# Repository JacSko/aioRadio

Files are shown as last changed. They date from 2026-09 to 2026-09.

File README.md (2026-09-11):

# aioRadio

## Project description
aioRadio (all-in-one Radio) is the ESP32-based system designed for FM, DAB and Online radio reception. It is based on Silicon Labs Si4684 chipset capable 
of decoding analog and digital radio. System consist of:
- Main custom-designed PCB with antenna input and 3,5mm jack audio output,
- st7796 480x320 LCD
- Rotary encoder with integrated push button

## Key features
- FM and DAB radio support
- Station list
- Band scan

## Building
System is based on esp-idf framework and works under freeRTOS control.

### Preconditions:
- download esp-idf toolchain
- source export.sh
### Build target
- go into project root directory and run:
```
./build_app.sh
```

### Build unit tests 
- go into project root directory and run:
```
./build_ut.sh
```



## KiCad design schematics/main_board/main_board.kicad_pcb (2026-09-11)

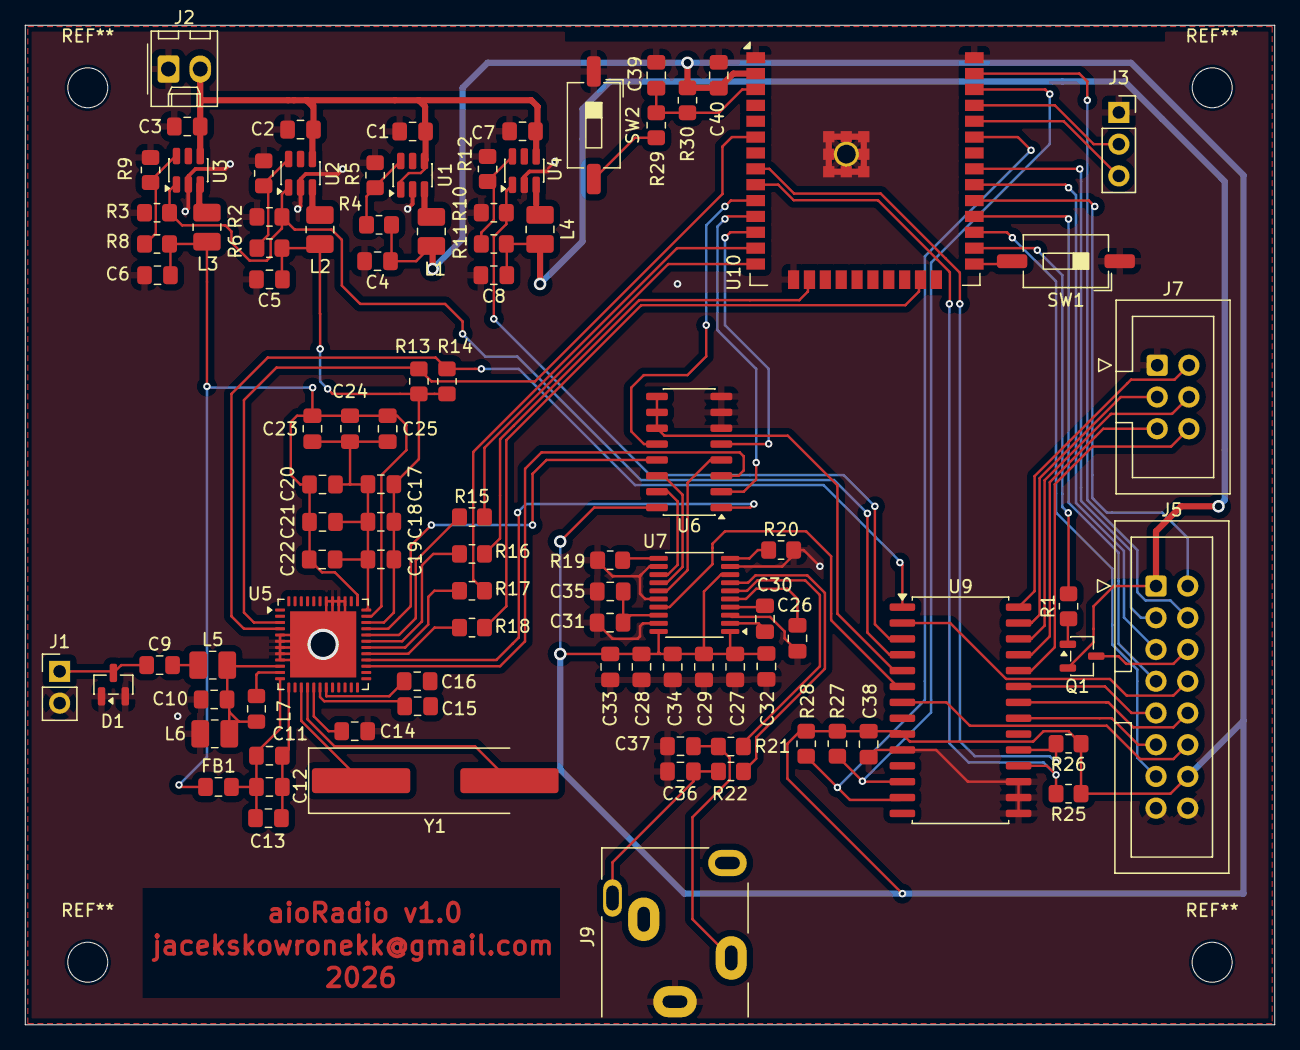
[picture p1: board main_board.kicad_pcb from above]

Board: 2 copper layers, 100.0 x 80.0 mm, 96 parts (0 on the bottom side), 87 nets.

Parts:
C1, C2, C3, C7: 4.7uF; C_0805_2012Metric_Pad1.18x1.45mm_HandSolder
C4, C5, C6, C8: 10uF; C_0805_2012Metric_Pad1.18x1.45mm_HandSolder
C9: 33p; C_0805_2012Metric_Pad1.18x1.45mm_HandSolder
C10: 2,7pF; C_0805_2012Metric_Pad1.18x1.45mm_HandSolder
C11, C27, C28, C29, C31, C38, C40: 100n; C_0805_2012Metric_Pad1.18x1.45mm_HandSolder
C12, C18, C21, C24: 2,2pF; C_0805_2012Metric_Pad1.18x1.45mm_HandSolder
C13, C17, C20, C23: 8,2pF; C_0805_2012Metric_Pad1.18x1.45mm_HandSolder
C14, C15, C16, C19, C22, C25, C39: 1u; C_0805_2012Metric_Pad1.18x1.45mm_HandSolder
C26, C30: 2,2uF; C_0805_2012Metric_Pad1.18x1.45mm_HandSolder
C32, C33, C34, C35: 10u; C_0805_2012Metric_Pad1.18x1.45mm_HandSolder
C36, C37: 2.2n; C_0805_2012Metric_Pad1.18x1.45mm_HandSolder
D1: BAV99; SOT-23
FB1: 1k; C_0805_2012Metric_Pad1.18x1.45mm_HandSolder
J1: ANT; PinHeader_1x02_P2.54mm_Vertical
J2: VCC_INPUT_5V0; Molex_KK-254_AE-6410-02A_1x02_P2.54mm_Vertical
J3: UART; PinSocket_1x03_P2.54mm_Vertical
J5: CONTROL_BOARD; IDC-Header_2x08_P2.54mm_Vertical
J7: GPIO_EXT; IDC-Header_2x03_P2.54mm_Vertical
J9: LineOut; Jack_3.5mm_CUI_SJ1-3515N_Horizontal
L1, L2, L3, L4: 2.2uH; L_1008_2520Metric_Pad1.43x2.20mm_HandSolder
L5: 18nH; L_1008_2520Metric_Pad1.43x2.20mm_HandSolder
L6: 120nH; L_1008_2520Metric_Pad1.43x2.20mm_HandSolder
L7: 22nH; L_0805_2012Metric_Pad1.15x1.40mm_HandSolder
Q1: BC807; SOT-23-3
R1: 330R; R_0805_2012Metric_Pad1.20x1.40mm_HandSolder
R2, R3, R10, R13, R14, R25, R26, R27, R28, R30: 10k; R_0805_2012Metric_Pad1.20x1.40mm_HandSolder
R4, R6, R11: 464k; R_0805_2012Metric_Pad1.20x1.40mm_HandSolder
R5, R7, R9, R12: 100k; R_0805_2012Metric_Pad1.20x1.40mm_HandSolder
R8: 200k; R_0805_2012Metric_Pad1.20x1.40mm_HandSolder
R15, R16, R17, R18: 100; R_0805_2012Metric_Pad1.20x1.40mm_HandSolder
R19, R20, R29: 0; R_0805_2012Metric_Pad1.20x1.40mm_HandSolder
R21, R22: 470R; R_0805_2012Metric_Pad1.20x1.40mm_HandSolder
SW1: BOOT_MODE; SW_DIP_SPSTx01_Slide_6.7x4.1mm_W8.61mm_P2.54mm_LowProfile
SW2: RESET; SW_DIP_SPSTx01_Slide_6.7x4.1mm_W8.61mm_P2.54mm_LowProfile
U1, U2, U3, U4: TLV62569DDC; SOT-23-6
U5: SI4684 SMD; QFN-48-1EP_7x7mm_P0.5mm_EP5.3x5.3mm
U6: CD74HC5053; SO-16_3.9x9.9mm_P1.27mm
U7: PCM5102; TSSOP-20_4.4x6.5mm_P0.65mm
U9: MCP23017_SO; SOIC-28W_7.5x17.9mm_P1.27mm
U10: ESP32-WROOM-32E; ESP32-WROOM-32E_handsolder
Y1: Crystal; Crystal_SMD_HC49-SD_HandSoldering

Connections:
/Audio/DAC_MUTE: U7.17 (XSMT), U9.6 (GPB5)
/Audio/I2S_SOURCE_SEL: U6.9 (S3), U6.10 (S2), U6.11 (S1), U9.5 (GPB4)
/Audio/SOC_I2S_DCLK: U6.2 (B0), U10.11 (IO26)
/Audio/SOC_I2S_DFS: U6.5 (C0), U10.12 (IO27)
/Audio/SOC_I2S_DIN: U6.12 (A0), U10.10 (IO25)
/Audio/TUNER_I2S_DCLK: U5.28 (DSF), U6.1 (B1)
/Audio/TUNER_I2S_DFS: U5.27 (DCLK), U6.3 (C1)
/Audio/TUNER_I2S_DIN: U5.33 (DOUT), U6.13 (A1)
/Audio/VCC_3V3: C4.1, C27.1, C28.1, C29.1, C32.1, C33.1, C34.1, C38.1, C40.1, J5.14, L1.2, R4.1, R25.1, R26.1, R27.1, R28.1, R30.1, U6.16 (VDD), U7.1 (CPVDD), U7.8 (AVDD), U7.20 (DVDD), U9.9 (VDD), U10.2 (VDD)
/BTN: J5.9, U9.23 (GPA2)
/DATA_REG: J5.7, U10.28 (IO17)
/ENC_A: J5.10, U9.22 (GPA1)
/ENC_B: J5.11, U9.21 (GPA0)
/ENC_BNT: J5.12, U9.7 (GPB6)
/IR: J5.13, U10.27 (IO16)
/LED_PWM: J5.6, Q1.3 (C)
/PSU/PWR_DISPLAY_3V3: C8.1, J5.1, L4.2, Q1.2 (E), R11.1
/PSU/PWR_DISPLAY_EN: R10.1, U4.1 (EN), U9.3 (GPB2)
/PSU/PWR_TUNER_1V8: C6.1, C20.2, C21.2, C22.2, C23.2, C24.2, C25.2, FB1.1, L3.2, R8.1, U5.35 (VMEM), U5.37 (VCORE)
/PSU/PWR_TUNER_3V3: C5.1, C17.2, C18.2, C19.2, L2.2, R6.1, R13.1, R14.1, U5.34 (VIO)
/PSU/PWR_TUNER_EN: R2.1, R3.1, U2.1 (EN), U3.1 (EN), U9.4 (GPB3)
/PSU/VCC_INPUT_5V0: C1.1, C2.1, C3.1, C7.1, J2.2, U1.1 (EN), U1.4 (VIN), U2.4 (VIN), U3.4 (VIN), U4.4 (VIN)
/RESET: J5.8, U9.2 (GPB1)
/SOC/DISPLAY_LED_PWM: R1.2, U10.26 (IO4)
/SOC/EXP_I2C_SCK: R27.2, U9.12 (SCK), U10.36 (IO22)
/SOC/EXP_I2C_SDA: R28.2, U9.13 (SDA), U10.33 (IO21)
/SOC/EXP_i2C_INT: R26.2, U9.19 (INTB), U10.8 (IO32)
/SOC/EXP_i2C_RESET: R25.2, U9.18 (~RESET), U10.9 (IO33)
/SOC/SOC_BOOT: SW1.2, U10.25 (IO0)
/SOC/SOC_RESET: R29.2, SW2.2
/SOC/SOC_UART_RX: J3.3, U10.34 (RXD0/IO3)
/SOC/SOC_UART_TX: J3.2, U10.35 (TXD0/IO1)
/SPI_CLK: J5.5, U10.30 (IO18)
/SPI_CS: J5.2, U10.29 (IO5)
/SPI_MISO: J5.3, U10.31 (IO19)
/SPI_MOSI: J5.4, U10.37 (IO23)
/TUNER_CLK: R17.2, U10.13 (IO14)
/TUNER_CS: R18.2, U10.23 (IO15)
/TUNER_INT: R13.2, U5.3 (~INTB), U10.6 (IO34)
/TUNER_MISO: R15.2, U10.14 (IO12)
/TUNER_MOSI: R16.2, U10.16 (IO13)
/TUNER_RESET: R14.2, U5.4 (~RSTB), U9.1 (GPB0)
/Tuner/ANT_IN: C9.1, D1.3 (K), J1.1 (In)
GND: C1.2, C2.2, C3.2, C4.2, C5.2, C6.2, C7.2, C8.2, C10.2, C14.2, C26.2, C27.2, C28.2, C29.2, C31.2, C32.2, C33.2, C34.2, C35.2, C36.2, C37.2, C38.2, C39.2, C40.2, D1.1 (K), D1.2 (A), J1.2 (Ext), J2.1, J3.1, J5.15, J5.16, J7.1, J9.S, L6.2, R2.2, R3.2, R5.2, R7.2, R9.2, R10.2, R12.2, R19.1, R20.2, SW1.1, SW2.1, U1.2 (GND), U2.2 (GND), U3.2 (GND), U4.2 (GND), U5.5 (SMODE), U5.6 (RFREF), U5.7 (RFREF), U5.8 (RFREF), U5.9 (RFREF), U5.39 (GNDD), U5.40 (GNDD), U5.41 (GNDD), U5.42 (GNDD), U5.49 (GND), U6.6 (INH), U6.7 (VEE), U6.8 (VSS), U7.3 (CPGND), U7.9 (AGND), U7.12 (SCK), U7.16 (FMT), U7.19 (DGND), U9.10 (VSS), U9.15 (A0), U9.16 (A1), U9.17 (A2), U10.1 (GND), U10.15 (GND), U10.38 (GND), U10.39 (GND)
unnamed: C9.2, L5.1
unnamed: C36.1, J9.R, R22.1
unnamed: C37.1, J9.T, R21.2
unnamed: J7.2, U9.28 (GPA7)
unnamed: J7.3, U9.27 (GPA6)
unnamed: J7.4, U9.26 (GPA5)
unnamed: J7.5, U9.25 (GPA4)
unnamed: J7.6, U9.24 (GPA3)
unnamed: Q1.1 (B), R1.1
unnamed: R4.2, R5.1, U1.6 (FB)
unnamed: L1.1, U1.3 (SW)
unnamed: R6.2, R7.1, U2.6 (FB)
unnamed: L2.1, U2.3 (SW)
unnamed: R8.2, R9.1, U3.6 (FB)
unnamed: L3.1, U3.3 (SW)
unnamed: R11.2, R12.1, U4.6 (FB)
unnamed: L4.1, U4.3 (SW)
unnamed: C11.2, C12.2, C13.2, U5.13 (ABYP)
unnamed: C14.1, U5.17 (DACREF)
unnamed: C17.1, C18.1, C19.1, C20.1, C21.1, C22.1, C23.1, C24.1, C25.1, U5.36 (DBYP)
unnamed: C15.1, U5.18 (LOUT)
unnamed: R15.1, U5.32 (MISO)
unnamed: R16.1, U5.31 (MOSI)
unnamed: C16.1, U5.19 (ROUT)
unnamed: R17.1, U5.30 (SCLK)
unnamed: R18.1, U5.29 (SSB)
unnamed: C11.1, C12.1, C13.1, FB1.2, U5.12 (VA)
unnamed: C10.1, L5.2, L6.1, L7.1, U5.10 (VHFI)
unnamed: L7.2, U5.11 (VHFSW)
unnamed: U5.15 (XTALI), Y1.1
unnamed: U5.16 (XTALO), Y1.2
unnamed: U6.14 (A), U7.14 (DIN)
unnamed: U6.15 (B), U7.13 (BCK)
unnamed: U6.4 (C), U7.15 (LRCK)
unnamed: C30.2, U7.4 (CAPM)
unnamed: C30.1, U7.2 (CAPP)
unnamed: R20.1, U7.10 (DEMP)
unnamed: R19.2, U7.11 (FLT)
unnamed: C31.1, C35.1, U7.18 (LDOO)
unnamed: R21.1, U7.6 (OUTL)
unnamed: R22.2, U7.7 (OUTR)
unnamed: C26.1, U7.5 (VNEG)
unnamed: C39.1, R29.1, R30.2, U10.3 (EN)

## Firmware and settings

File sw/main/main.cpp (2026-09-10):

#include <thread>
#include <memory>
#include <chrono>
#include "Log.h"
#include "GPIOProvider.h"
#include "GPIOMapping.h"
#include "IDeviceDriver.h"
#include "TunerManager.h"
#include "IDABTuner.h"
#include "IFMTuner.h"
#include "UserControl.h"
#include "DisplayDriver.h"
#include "IAudioControl.h"

#include "esp_heap_caps.h"

static const char* TAG = "AIO_RADIO";
using namespace drivers;

class aioRadio : public drivers::encoder::IEncoderListener
{
public:
   aioRadio():
   m_provider(gpio::mcp23017::i2cConfig{
            .i2cAddress = 0x20,
            .clockSpeedHz = 400000,
            .sclPin = static_cast<uint16_t>(drivers::gpio::GPIO::GPIO_I2C_SCL),
            .sdaPin = static_cast<uint16_t>(drivers::gpio::GPIO::GPIO_I2C_SDA),
            .resetPin = static_cast<uint16_t>(drivers::gpio::GPIO::GPIO_I2C_RESET),
            .interruptPin = static_cast<uint16_t>(drivers::gpio::GPIO::GPIO_I2C_INT),
             }),
   m_displayDriver(m_provider)
   {

   }
   void onEvent(const drivers::encoder::IEncoderListener::Event& event) override
   {
      AIO_LOGE(TAG, "Encoder event received: type=%s, diff=%d", drivers::encoder::IEncoderListener::eventName(event.type), event.diff);
   }
   void run()
   {
      bool result = false;

      result = m_displayDriver.initialize();
      AIO_LOGI(TAG, "DisplayDriver init resultL: %d", result);

      m_mainGUI = display::gui::IMainGUI::create();
      m_mainGUI->initialize(display::gui::ViewType::DAB);
      AIO_LOGI(TAG, "MainGUI created!");

      m_tunerDriver = tuner::devicedriver::IDeviceDriver::create(m_provider);
      result = m_tunerDriver->initialize();
      AIO_LOGI(TAG, "Device driver init result: %d", result);

      m_dabTuner = tuner::dab::IDABTuner::create(*m_tunerDriver);
      AIO_LOGI(TAG, "DABTuner created!");

      m_fmTuner = tuner::fm::IFMTuner::create(*m_tunerDriver);
      AIO_LOGI(TAG, "FMTuner created!");

      m_audioControl = audio::IAudioControl::create(*m_tunerDriver);
      AIO_LOGI(TAG, "AudioControl created!");

      m_userControl = std::make_unique<control::UserControl>(m_provider.getDriver(), *m_mainGUI, *m_audioControl);
      AIO_LOGI(TAG, "UserControl created!");

      m_tunerManager = std::make_unique<tuner::manager::TunerManager>(*m_mainGUI, *m_dabTuner, *m_fmTuner, *m_audioControl);

      while(1)
      {
         std::this_thread::sleep_for(std::chrono::milliseconds(1000));
      }
   }
private:
   gpio::GPIOProvider m_provider;
   display::driver::DisplayDriver m_displayDriver;
   std::unique_ptr<display::gui::IMainGUI> m_mainGUI;
   std::unique_ptr<audio::IAudioControl> m_audioControl;
   std::unique_ptr<control::UserControl> m_userControl;
   std::unique_ptr<tuner::devicedriver::IDeviceDriver> m_tunerDriver;
   std::unique_ptr<tuner::dab::IDABTuner> m_dabTuner;
   std::unique_ptr<tuner::fm::IFMTuner> m_fmTuner;
   std::unique_ptr<tuner::manager::TunerManager> m_tunerManager;
};

extern "C" void app_main(void )
{
   // AIO_LOGE(TAG, "[before aioReadio creation] Free heap: %zu, largest block: %zu", heap_caps_get_free_size(MALLOC_CAP_DEFAULT), heap_caps_get_largest_free_block(MALLOC_CAP_DEFAULT));
   aioRadio radio;
   // AIO_LOGE(TAG, "[after aioRadio creation] Free heap: %zu, largest block: %zu", heap_caps_get_free_size(MALLOC_CAP_DEFAULT), heap_caps_get_largest_free_block(MALLOC_CAP_DEFAULT));
   radio.run();
}

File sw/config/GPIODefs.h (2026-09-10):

#pragma once
#include <cstdint>

namespace drivers::gpio {

   static constexpr uint16_t SOC_GPIO0    = 0;
   static constexpr uint16_t SOC_GPIO2    = 2;
   static constexpr uint16_t SOC_GPIO4    = 4;
   static constexpr uint16_t SOC_GPIO5    = 5;
   static constexpr uint16_t SOC_GPIO12   = 12;
   static constexpr uint16_t SOC_GPIO13   = 13;
   static constexpr uint16_t SOC_GPIO14   = 14;
   static constexpr uint16_t SOC_GPIO15   = 15;
   static constexpr uint16_t SOC_GPIO16   = 16;
   static constexpr uint16_t SOC_GPIO17   = 17;
   static constexpr uint16_t SOC_GPIO18   = 18;
   static constexpr uint16_t SOC_GPIO19   = 19;
   static constexpr uint16_t SOC_GPIO20   = 20;
   static constexpr uint16_t SOC_GPIO21   = 21;
   static constexpr uint16_t SOC_GPIO22   = 22;
   static constexpr uint16_t SOC_GPIO23   = 23;
   static constexpr uint16_t SOC_GPIO25   = 25;
   static constexpr uint16_t SOC_GPIO26   = 26;
   static constexpr uint16_t SOC_GPIO27   = 27;
   static constexpr uint16_t SOC_GPIO32   = 32;
   static constexpr uint16_t SOC_GPIO33   = 33;
   static constexpr uint16_t SOC_GPIO34   = 34;
   static constexpr uint16_t SOC_GPIO_MAX = 0x9F;
   static constexpr uint16_t I2C_GPIOA0   = 0xA0;
   static constexpr uint16_t I2C_GPIOA1   = 0xA1;
   static constexpr uint16_t I2C_GPIOA2   = 0xA2;
   static constexpr uint16_t I2C_GPIOA3   = 0xA3;
   static constexpr uint16_t I2C_GPIOA4   = 0xA4;
   static constexpr uint16_t I2C_GPIOA5   = 0xA5;
   static constexpr uint16_t I2C_GPIOA6   = 0xA6;
   static constexpr uint16_t I2C_GPIOA7   = 0xA7;
   static constexpr uint16_t I2C_GPIOB0   = 0xB0;
   static constexpr uint16_t I2C_GPIOB1   = 0xB1;
   static constexpr uint16_t I2C_GPIOB2   = 0xB2;
   static constexpr uint16_t I2C_GPIOB3   = 0xB3;
   static constexpr uint16_t I2C_GPIOB4   = 0xB4;
   static constexpr uint16_t I2C_GPIOB5   = 0xB5;
   static constexpr uint16_t I2C_GPIOB6   = 0xB6;
   static constexpr uint16_t I2C_GPIOB7   = 0xB7;
   static constexpr uint16_t I2C_GPIO_MAX = 0xFF;

}

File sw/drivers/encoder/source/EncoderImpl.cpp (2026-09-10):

#include "EncoderImpl.h"
#include "Log.h"

namespace drivers::encoder
{
using namespace gpio;

static const char* TAG = "Encoder";
static const int TASK_STACK_SIZE = 4096;
static const int TASK_NOTIFY_WAIT_MS = 1000;
static const int TASK_PRIORITY = 2;
static const mcp23017::PIN PIN_A = mcp23017::PIN::GPIOA1;
static const mcp23017::PIN PIN_B = mcp23017::PIN::GPIOA0;
static const mcp23017::PIN PIN_BUTTON = mcp23017::PIN::GPIOB6;

std::unique_ptr<IEncoder> IEncoder::create(drivers::gpio::mcp23017::IMCP23017& driver, IEncoderListener& listener)
{
    return std::make_unique<EncoderImpl>(driver, listener);
}

static void mcp_gpio_listener(mcp23017::PIN pin, bool state , void* arg)
{
   EncoderImpl* enc = static_cast<EncoderImpl*>(arg);
   enc->onInterrupt(pin, state);
}

EncoderImpl::EncoderImpl(drivers::gpio::mcp23017::IMCP23017& driver, IEncoderListener& listener):
m_driver(driver),
m_listener(listener),
m_edgesMutex(xSemaphoreCreateMutex())
{
   AIO_ASSERT(m_edgesMutex != nullptr, TAG, "Failed to create listeners mutex");
   openEncoderPin(PIN_A);
   openEncoderPin(PIN_B);
   openEncoderPin(PIN_BUTTON);
}
EncoderImpl::~EncoderImpl()
{
   closeEncoderPin(PIN_A);
   closeEncoderPin(PIN_B);
   closeEncoderPin(PIN_BUTTON);
}
void EncoderImpl::openEncoderPin(mcp23017::PIN pin)
{
   m_driver.setPullup(pin, mcp23017::Pullup::ENABLED);
   m_driver.setInterruptCompare(pin, mcp23017::InterruptCompare::COMPARE_PREVIOUS);
   m_driver.setDirection(pin,mcp23017::Direction::INPUT);
   m_driver.setListener(pin, mcp_gpio_listener, this);
}
void EncoderImpl::closeEncoderPin(mcp23017::PIN pin)
{
   m_driver.removeListener(pin);
}
void EncoderImpl::onInterrupt(mcp23017::PIN pin, bool state)
{
   IEncoderListener::Event event = {};
   switch(pin)
   {
      case PIN_A:
         AIO_LOGD(TAG, "Interrupt on encoder pin A, state: %d", static_cast<int>(state));
         xSemaphoreTake(m_edgesMutex, portMAX_DELAY);
         m_lastEdges <<= 8;
         m_lastEdges |= state ? PIN_A_RISING : PIN_A_FALLING;
         checkEncoderMove();
         xSemaphoreGive(m_edgesMutex);
         break;
      case PIN_B:
         AIO_LOGD(TAG, "Interrupt on encoder pin B, state: %d", static_cast<int>(state));
         xSemaphoreTake(m_edgesMutex, portMAX_DELAY);
         m_lastEdges <<= 8;
         m_lastEdges |= state? PIN_B_RISING : PIN_B_FALLING;
         checkEncoderMove();
         xSemaphoreGive(m_edgesMutex);
         break;
      case PIN_BUTTON:
         AIO_LOGD(TAG, "Interrupt on encoder button, state: %d", static_cast<int>(state));
         event.type = state? IEncoderListener::Event::Type::BUTTON_RELEASED:
                             IEncoderListener::Event::Type::BUTTON_PRESSED;
         event.diff = 0;
         m_listener.onEvent(event);
         break;
      default:
         AIO_LOGW(TAG, "Interrupt on unknown GPIO ID: %.2x", static_cast<int>(pin));
         break;
   }
}
void EncoderImpl::checkEncoderMove()
{
   static const uint32_t CW_PATTERN = (PIN_A_FALLING << 24) | (PIN_B_FALLING << 16) | (PIN_A_RISING << 8) | (PIN_B_RISING);
   static const uint32_t CCW_PATTERN = (PIN_B_FALLING << 24) | (PIN_A_FALLING << 16) | (PIN_B_RISING << 8) | (PIN_A_RISING);

   if (m_lastEdges == CW_PATTERN)
   {
      IEncoderListener::Event event = {};
      event.type = IEncoderListener::Event::Type::ROTATE;
      event.diff = -1;
      m_listener.onEvent(event);
      m_lastEdges = 0;
   }
   else if (m_lastEdges == CCW_PATTERN)
   {
      IEncoderListener::Event event = {};
      event.type = IEncoderListener::Event::Type::ROTATE;
      event.diff = 1;
      m_listener.onEvent(event);
      m_lastEdges = 0;
   }
}

} // namespace drivers

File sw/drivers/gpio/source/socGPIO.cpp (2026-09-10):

#include <vector>

#include "socGPIO.h"
#include "TableConverter.hpp"
#include "driver/gpio.h"
#include "Log.h"

namespace drivers::gpio
{

static const char* TAG = "socGPIO";
static const int TASK_STACK_SIZE = 4096;
static const int TASK_NOTIFY_WAIT_MS = 1000;
static const int TASK_PRIORITY = 2;

static void IRAM_ATTR gpio_soc_isr_handler(void* arg)
{
   socGPIO* gpio = static_cast<socGPIO*>(arg);
   gpio->onInterrupt();
}

static void taskFunction(void* arg)
{
   socGPIO* gpio = static_cast<socGPIO*>(arg);
   gpio->task();
   vTaskDelete(NULL);
}

socGPIO::socGPIO(uint16_t id, const std::string&& name) :
m_id(id),
m_name(std::move(name)),
m_task(nullptr),
m_listenersMutex(xSemaphoreCreateMutex())
{
   AIO_LOGI(TAG, "[%s] creating", m_name.c_str());
   assert(m_listenersMutex != nullptr);
   gpio_reset_pin(static_cast<gpio_num_t>(m_id));
}
socGPIO::~socGPIO()
{
   AIO_LOGI(TAG, "[%s] destroying", m_name.c_str());
   disableInterrupts();
   gpio_reset_pin(static_cast<gpio_num_t>(m_id));
}
void socGPIO::onInterrupt()
{
   //This method is called in ISR context
   ESP_DRAM_LOGE(DRAM_STR("SOC"), "task notify from ISR for GPIO %u", static_cast<unsigned int>(m_id));
   vTaskNotifyGiveFromISR(m_task, nullptr);
}
void socGPIO::task()
{
   for (;;)
   {
      int eventReady = ulTaskNotifyTake(true, pdMS_TO_TICKS(TASK_NOTIFY_WAIT_MS));
      if (eventReady)
      {
         handleInterrupt();
      }
   }
}
void socGPIO::handleInterrupt()
{
   AIO_LOGV(TAG, "[%s] interrupt received, reading state...", m_name.c_str());
   int level = gpio_get_level(static_cast<gpio_num_t>(m_id));
   AIO_LOGV(TAG, "[%s] is %u, calling listeners...", m_name.c_str(), level);
   xSemaphoreTake(m_listenersMutex, portMAX_DELAY);
   if (m_listener)
   {
      m_listener->onInterrupt(static_cast<GPIO>(m_id), static_cast<State>(level ?
                                                       State::HIGH :
                                                       State::LOW));
   }
   xSemaphoreGive(m_listenersMutex);
}
bool socGPIO::createTask()
{
   AIO_LOGI(TAG, "[%s] creating interrupt task", m_name.c_str());
   char taskName[16];
   snprintf(taskName, sizeof(taskName), "socGPIO_%u", static_cast<unsigned int>(m_id));
   BaseType_t result = xTaskCreate(taskFunction, taskName, TASK_STACK_SIZE, this, TASK_PRIORITY, &m_task);
   AIO_LOGE_IF(result != pdPASS, TAG, "[%s] Failed to create interrupt task, error %d", m_name.c_str(), result);
   return result == pdPASS;
}
void socGPIO::destroyTask()
{
   AIO_LOGI(TAG, "[%s] destroying interrupt task", m_name.c_str());
   if (m_task != nullptr)
   {
      vTaskDelete(m_task);
      m_task = nullptr;
   }
}
bool socGPIO::isConfigValid(const Config& config)
{
   if (!GPIO_IS_VALID_GPIO(static_cast<gpio_num_t>(m_id)))
   {
      AIO_LOGE(TAG, "[%s] this is not a valid ID", m_name.c_str());
      return false;
   }
   if (config.direction == Direction::OUTPUT &&
       !GPIO_IS_VALID_OUTPUT_GPIO(static_cast<gpio_num_t>(m_id)))
   {
      AIO_LOGE(TAG, "[%s] cannot be configured as output", m_name.c_str());
      return false;
   }
   if (config.listener &&
       config.direction != Direction::INPUT)
   {
      AIO_LOGE(TAG, "[%s] interrupt can only be configured for input direction", m_name.c_str());
      return false;
   }
   return true;
}
bool socGPIO::configure(const Config& config)
{
   AIO_LOGI(TAG, "[%s] configuring", m_name.c_str());
   bool isValid = isConfigValid(config);
   if (isValid)
   {
      gpio_config_t io_conf = {};
      io_conf.pin_bit_mask = (1ULL << static_cast<uint32_t>(m_id));
      io_conf.mode = (config.direction == Direction::INPUT) ? GPIO_MODE_INPUT : GPIO_MODE_OUTPUT;
      io_conf.pull_up_en = (config.pullMode == PullMode::PULL_UP) ? GPIO_PULLUP_ENABLE : GPIO_PULLUP_DISABLE;
      io_conf.pull_down_en = (config.pullMode == PullMode::PULL_DOWN) ? GPIO_PULLDOWN_ENABLE : GPIO_PULLDOWN_DISABLE;
      io_conf.intr_type = GPIO_INTR_DISABLE;
      esp_err_t err = gpio_config(&io_conf);
      if (err != ESP_OK)
      {
         AIO_LOGE(TAG, "[%s] Failed to configure GPIO", m_name.c_str());
         return false;
      }
      if (config.direction == Direction::OUTPUT)
      {
         setState(config.state);
      }
      if (config.listener)
      {
         enableInterrupts(config.listener, config.interruptEdge);
      }
      else
      {
         disableInterrupts();
      }
      return true;
   }
   else
   {
      AIO_LOGE(TAG, "[%s] invalid configuration", m_name.c_str());
      return false;
   }
}
bool socGPIO::setState(State state)
{
   AIO_LOGD(TAG, "[%s] setting state to %s", m_name.c_str(), (state == State::HIGH) ? "HIGH" : "LOW");
   return gpio_set_level(static_cast<gpio_num_t>(m_id), (state == State::HIGH) ? 1 : 0) == ESP_OK;
}
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

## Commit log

2026-09-10 Initial code drop for AIORadio
    [Audio.kicad_sch, Control.kicad_sch, Display.kicad_sch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]
2026-09-11 Update PCB's 3d models
    [main_board.kicad_pcb]
